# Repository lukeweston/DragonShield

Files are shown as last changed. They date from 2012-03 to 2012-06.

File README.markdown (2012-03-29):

DragonShield v1.0

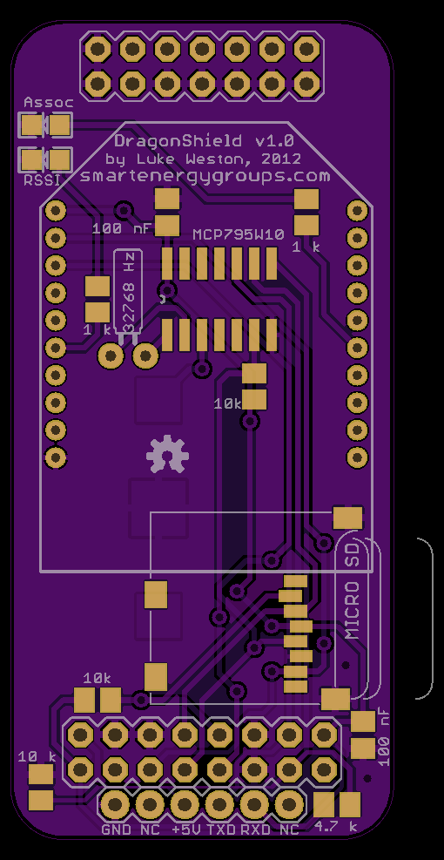
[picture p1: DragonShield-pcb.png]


Dragino daughterboard with SPI real-time clock, socket for XBee 802.15.4 module or similar "Bee" module and micro-SD card socket.

The XBee module is simply connected to the serial UART on the AR2317.

The RTC and the micro-SD card are connected to the AR2317's GPIO pins, and an appropriate SPI interface can be implemented through an appropriate driver within the OS.

More documentation to be written in future.

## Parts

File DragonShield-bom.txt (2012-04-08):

																			
DragonShield bill of materials
																			
Resistors (Qty:)	Component IDs	Value			Packaging	Digi-Key SKU		Unit Price (USD)	Subtotal	Notes
												
3			R1, R2, R4	10 k			SMD 0805	311-10KARCT-ND		0.0170			0.0510
1			R3		4.7 k			SMD 0805	311-4.7KARCT-ND		0.0170			0.0170
2			R5, R6		1 k			SMD 0805	311-1.0KARCT-ND		0.0170			0.0340
																			
Capacitors																			
2			C1, C2		100 nF			SMD 0805	311-1361-1-ND		0.0310			0.0620
																			
Semiconductors																			
2			LED1, LED2	Green LED		SMD 0805	754-1131-1-ND		0.1600			0.3200
1			IC1		MCP795W10		SOIC-14		MCP795W10-I/SL-ND	2.1200			2.1200
																			
Miscellaneous																			
1			Q1		32768 Hz		TC26		535-9032-ND		0.2500			0.2500
1			B1		SMD CR1220 clip				3000K-ND		0.5700			0.5700
1			N/A		CR1220 3V cell				SY033-ND		0.7600			0.7600
1			J2		Micro-SD card socket			101-00660-68-6-1-ND	1.9700			1.9700
1			J4		1x6 0.1" pin header			3M9451-ND		0.3300			0.3300
2			J5a, J5b	2.0mm 10-pin header skt			S5751-10-ND		1.11			2.2200
1			J1		2x8 0.1" pin header			N/A								
1			J3		2x7 0.1" pin header			N/A								
															Total:	12.7260	(Excludes PCBs and XBee.)
																	(And shipping.)

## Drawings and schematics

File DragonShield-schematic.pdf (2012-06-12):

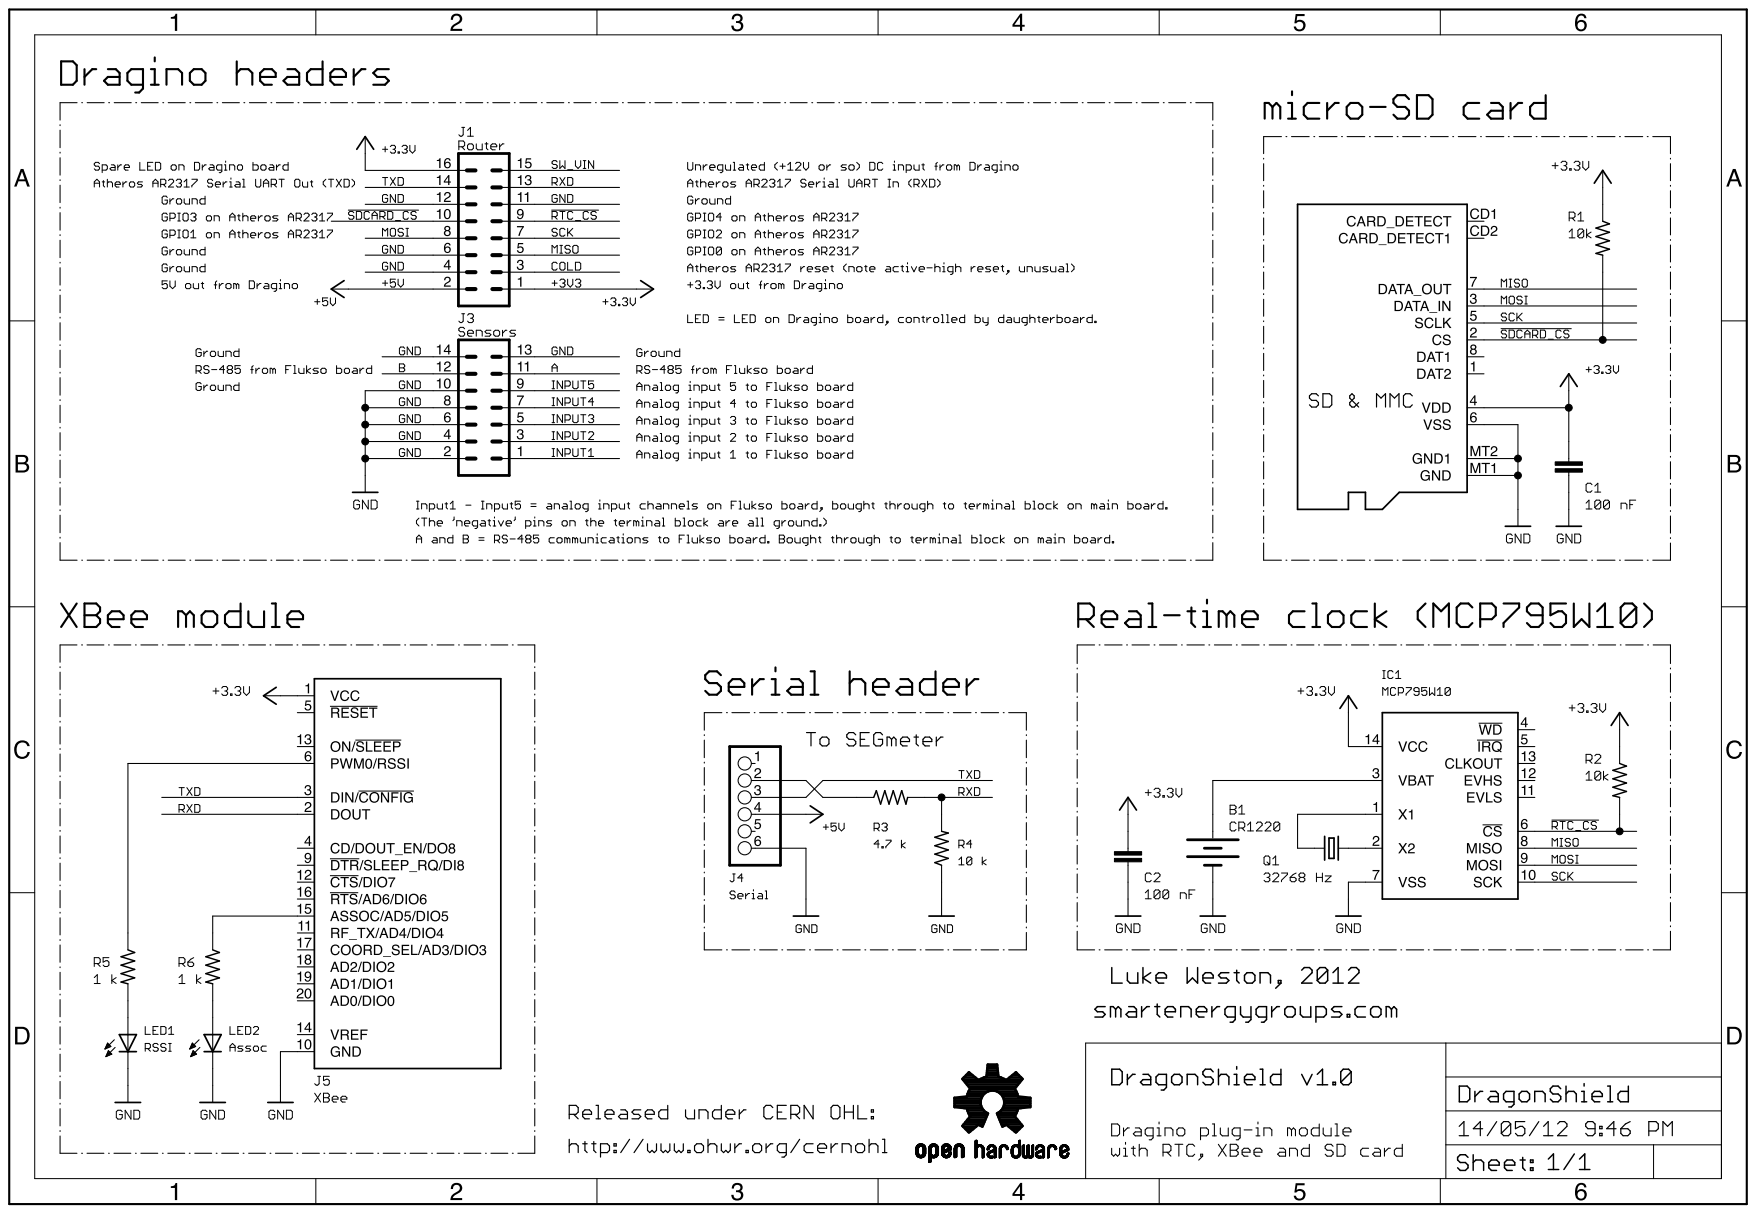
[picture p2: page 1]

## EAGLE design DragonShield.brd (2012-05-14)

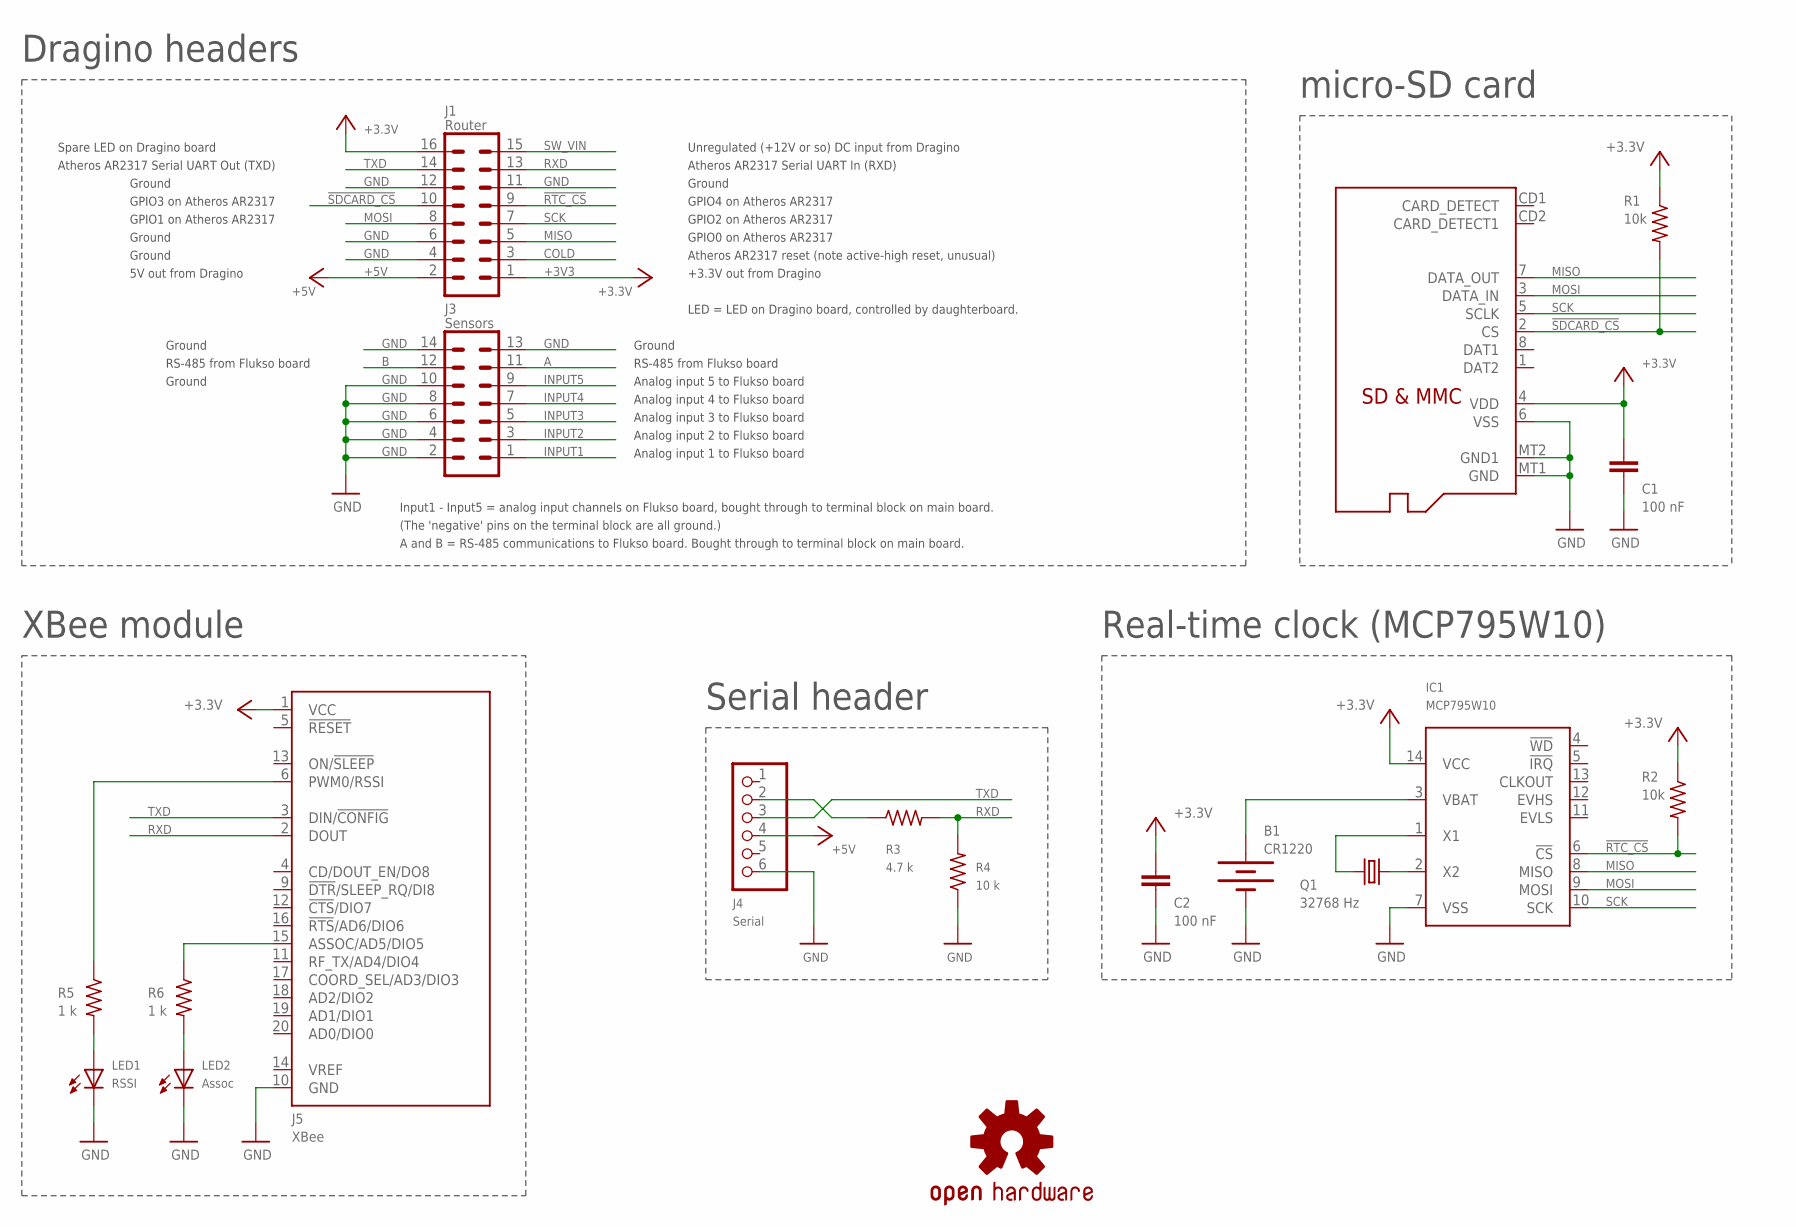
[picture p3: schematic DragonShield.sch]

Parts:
B1: CR1220; BATTCON_12MM
C1, C2: 100 nF; C0805K
IC1: MCP795W10; SOIC14
J1: Router; MA08-2
J2: MICROSD
J3: Sensors; MA07-2
J4: Serial; 1X06
J5: XBee; XBEE-PRO
LED1: RSSI; LED-0805-LARGE
LED2: Assoc; LED-0805-LARGE
Q1: 32768 Hz; TC26H
R1, R2: 10k; M0805
R3: 4.7 k; M0805
R4: 10 k; M0805
R5, R6: 1 k; M0805
U$: OSHW-LOGOS; OSHW-LOGO-S

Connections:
!RTC_CS: IC1.6 (!CS), J1.9, R2.2
!SDCARD_CS: J1.10, J2.2 (CS), R1.2
+3V3: C1.2, C2.2, IC1.14 (VCC), J1.1, J1.16, J2.4 (VDD), J5.1 (VCC), R1.1, R2.1
+5V: J1.2, J4.4
A: J3.11
B: J3.12
COLD: J1.3
GND: B1.GND (-), C1.1, C2.1, IC1.7 (VSS), J1.4, J1.6, J1.11, J1.12, J2.6 (VSS), J2.MT1 (GND), J2.MT2 (GND1), J3.2, J3.4, J3.6, J3.8, J3.10, J3.13, J3.14, J4.6, J5.10 (GND), LED1.C, LED2.C, R4.1
INPUT1: J3.1
INPUT2: J3.3
INPUT3: J3.5
INPUT4: J3.7
INPUT5: J3.9
MISO: IC1.8 (MISO), J1.5, J2.7 (DATA_OUT)
MOSI: IC1.9 (MOSI), J1.8, J2.3 (DATA_IN)
unnamed: J4.2, R3.1
unnamed: IC1.1 (X1), Q1.2
unnamed: IC1.2 (X2), Q1.1
unnamed: LED2.A, R6.2
unnamed: J5.15 (ASSOC/AD5/DIO5), R6.1
unnamed: LED1.A, R5.2
unnamed: J5.6 (PWM0/RSSI), R5.1
unnamed: B1.PWR@1 (+), IC1.3 (VBAT)
RXD: J1.13, J5.2 (DOUT), R3.2, R4.2
SCK: IC1.10 (SCK), J1.7, J2.5 (SCLK)
SW_VIN: J1.15
TXD: J1.14, J4.3, J5.3 (DIN/!CONFIG)

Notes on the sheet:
A and B = RS-485 communications to Flukso board. Bought through to terminal block on main board.
Input1 - Input5 = analog input channels on Flukso board, bought through to terminal block on main board.
(The 'negative' pins on the terminal block are all ground.)
RS-485 from Flukso board
Analog input 5 to Flukso board
+3.3V out from Dragino
GPIO0 on Atheros AR2317
GPIO2 on Atheros AR2317
GPIO4 on Atheros AR2317
GPIO3 on Atheros AR2317
GPIO1 on Atheros AR2317
5V out from Dragino
Analog input 4 to Flukso board
Analog input 3 to Flukso board
Analog input 2 to Flukso board
Analog input 1 to Flukso board
Spare LED on Dragino board
Atheros AR2317 Serial UART Out (TXD)
Atheros AR2317 Serial UART In (RXD)
Unregulated (+12V or so) DC input from Dragino
Atheros AR2317 reset (note active-high reset, unusual)
Ground
LED = LED on Dragino board, controlled by daughterboard.
Dragino headers
XBee module
Real-time clock (MCP795W10)
micro-SD card
Serial header

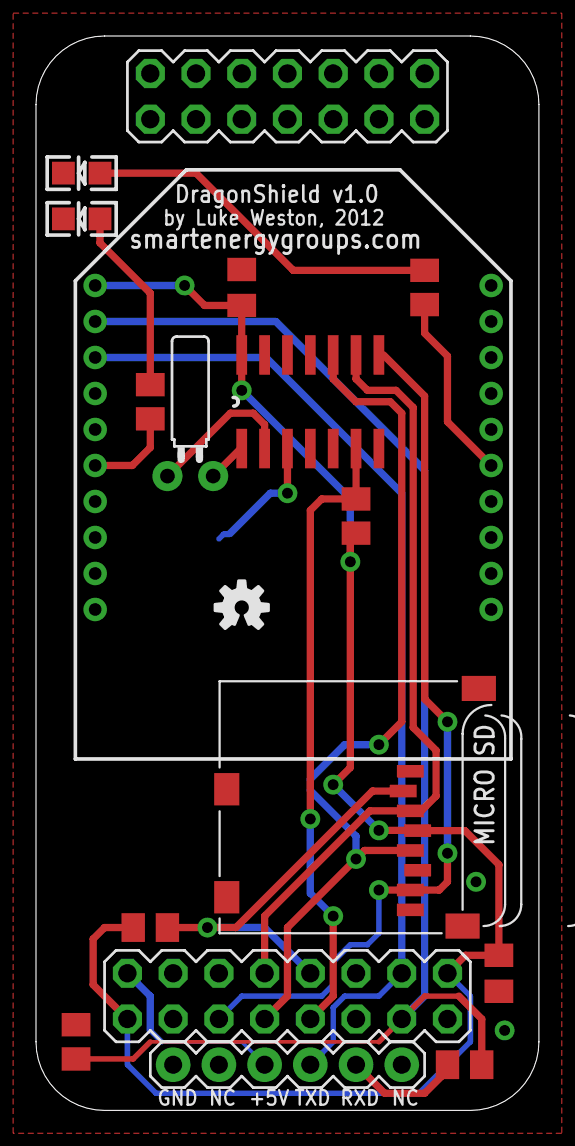
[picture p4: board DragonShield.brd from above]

Board: 2 copper layers, 27.9 x 59.7 mm, 19 parts (1 on the bottom side), 18 nets.

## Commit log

2012-04-03 added serial header
    [DragonShield.brd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]
2012-04-04 fixed mask DRC errors
    [DragonShield.brd, DragonShield.sch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]

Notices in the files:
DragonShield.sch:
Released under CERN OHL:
